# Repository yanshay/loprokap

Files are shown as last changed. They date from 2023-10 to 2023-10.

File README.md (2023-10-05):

# LoProKap

A wireless split keyboard with keys layout somewhat compatible with Kinesis Advantage Pro 360<sup>TM</sup>.
Designed using [Ergogen](https://ergogen.xyz/) and my [Ergogen Routing System](https://github.com/yanshay/ergogen-stuff)

> **Warning**
>
> This keyboard is still under development and not ready for manufacturing.

## Background

I own a [Kinesis Advantage Pro 360 keyboard](https://kinesis-ergo.com/shop/adv360pro/). 

With its concave structure, ergonomically it's a **great** keyboard but that costs in it not being very mobile.

Since I started using it I find it uncomfortable/confusing to use a standard keyboard when the Kinesis is not with me, so wanted to build a more mobile low profile keyboard that shares the same zmk configuration, and for that needed a compatible key layout. I also wanted keys to be layed out in a way that works on a non concave keyboard. This keyboard is the result.

The keyboard is developed using Ergogen and KiCad.

Ergogen is geat for layout of keys and other components however lacks any support for routing the PCB. With basic Ergogen usage every change in Ergogen cofig requires routing the keyboard from scratch.

Faced with that challenge, I developed a system for easy routing that complements Ergogen, where the routes are 'recorded' in Kicad as Ergogen footprint config using a KiCad plugin + routes are generated by Ergogen using the router footprint.

Both the KiCad Plugin and the Ergogen Footprint are available at https://github.com/yanshay/ergogen-stuff .

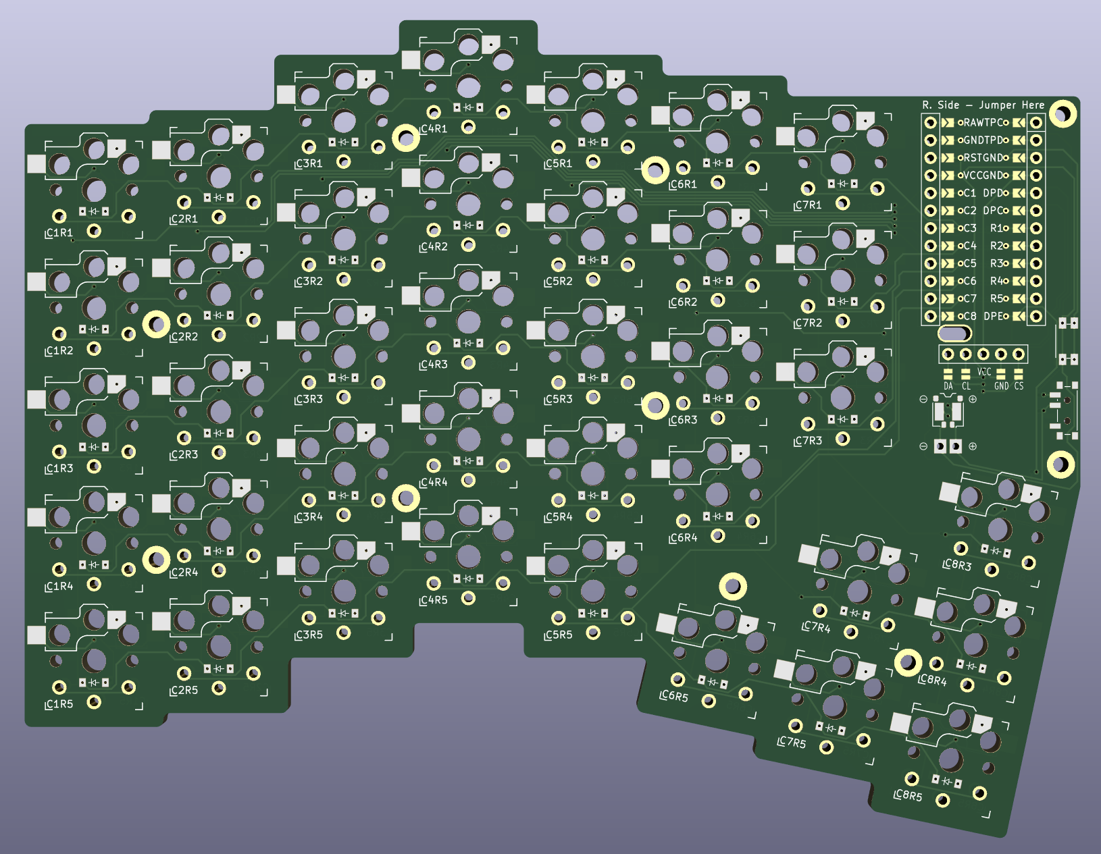
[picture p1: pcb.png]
Keyboard PCB Image


## Building the keyboard

1. Clone this repo
2. Change into the ergogen_src/footprints and execute the download_fps.sh to fetch the footprints from the relevant repositories
3. From the root folder run Build.sh
4. Output pcbs will be in pcbs folder (the repository already includes a version of the built pcb)

There are several scripts at the repo root that are specific to my systm folder structure that include some helpful functionality for easier workflow with Ergogen.

## Credits and Acknowledgements
- [Ergogen](https://ergogen.xyz/)

- [@infused-kim](https://github.com/infused-kim)
  - https://github.com/infused-kim/kb_ergogen_fp - basis for the footprints used, some of them were improved for this keyboard and therefore are in this repo
  - https://github.com/infused-kim/kb_think_corney - referenced used for learning
  - Thanks for the assistance over Ergogen Discord

- Everyone else who contributed to @infused-kim work and are mentioned in his repos, so indirectly contributed to this as well.

## License

**TLDR:**

- Personal use with attribution
- Commercial use not allowed
- Distribution under same license as the original

This work is licensed under a
[Creative Commons Attribution-ShareAlike 4.0 International License][cc-by-sa].

[][cc-by-sa]

[cc-by-sa]: http://creativecommons.org/licenses/by-sa/4.0/
[cc-by-sa-image]: https://licensebuttons.net/l/by-sa/4.0/88x31.png
[cc-by-sa-shield]: https://img.shields.io/badge/License-CC%20BY--SA%204.0-lightgrey.svg

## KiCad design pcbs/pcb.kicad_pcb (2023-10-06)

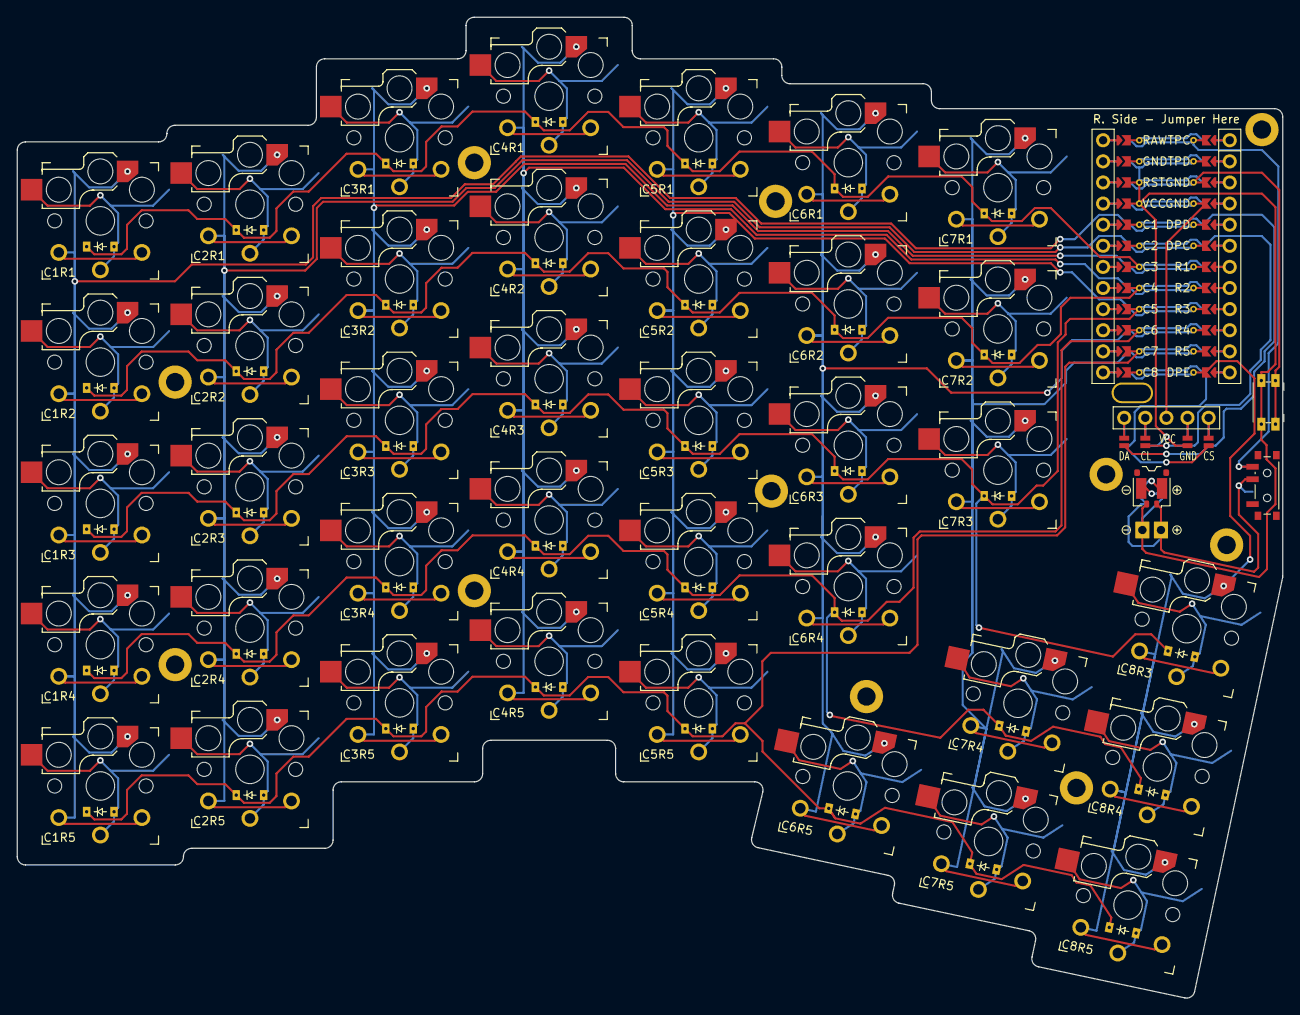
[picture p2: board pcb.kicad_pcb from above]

Board: 2 copper layers, 152.3 x 118.0 mm, 97 parts (0 on the bottom side), 63 nets.

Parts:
CONN1: conn_molex_pico_ezmate_1x02
D1, D2, D3, D4, D5, D6, D7, D8, D9, D10, D11, D12, D13, D14, D15, D16, D17, D18, D19, D20, D21, D22, D23, D24, D25, D26, D27, D28, D29, D30, D31, D32, D33, D34, D35, D36, D37, D38: ComboDiode
DISP1: nice!view
H1, H2, H3, H4, H5, H6, H7, H8, H9, H10, H11, H12: mounting_hole
ICON1, ICON2: icon_bat
MCU1: nice_nano
PAD1, PAD2: pads
S1, S2, S3, S4, S5, S6, S7, S8, S9, S10, S11, S12, S13, S14, S15, S16, S17, S18, S19, S20, S21, S22, S23, S24, S25, S26, S27, S28, S29, S30, S31, S32, S33, S34, S35, S36, S37, S38: PG1350
SW1: Panasonic_EVQPUJ_EVQPUA
SW2: power_switch

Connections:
BAT_P: CONN1.1, PAD1.1, PAD1.2, PAD2.1, SW2.2, SW2.5
C1: MCU1.5, S1.1, S2.1, S3.1, S4.1, S5.1
C2: MCU1.6, S6.1, S7.1, S8.1, S9.1, S10.1
C3: MCU1.7, S11.1, S12.1, S13.1, S14.1, S15.1
C4: MCU1.8, S16.1, S17.1, S18.1, S19.1, S20.1
C5: MCU1.9, S21.1, S22.1, S23.1, S24.1, S25.1
C6: MCU1.10, S26.1, S27.1, S28.1, S29.1, S33.1
C7: MCU1.11, S30.1, S31.1, S32.1, S34.1, S35.1
C8: MCU1.12, S36.1, S37.1, S38.1
DISP1_1: DISP1.1, DISP1.14, DISP1.27
DISP1_2: DISP1.2, DISP1.15, DISP1.26
DISP1_4: DISP1.4, DISP1.16, DISP1.25
DISP1_5: DISP1.5, DISP1.17, DISP1.24
DPC: DISP1.11, DISP1.21, MCU1.119
DPD: DISP1.10, DISP1.20, MCU1.120
DPE: DISP1.13, DISP1.23, MCU1.113
GND: CONN1.2, DISP1.12, DISP1.22, MCU1.2, MCU1.121, MCU1.122, PAD1.1, PAD1.2, PAD2.2, SW1.1
R1: D5.1, D10.1, D15.1, D20.1, D25.1, D29.1, D32.1, MCU1.118
R2: D4.1, D9.1, D14.1, D19.1, D24.1, D28.1, D31.1, MCU1.117
R3: D3.1, D8.1, D13.1, D18.1, D23.1, D27.1, D30.1, D38.1, MCU1.116
R4: D2.1, D7.1, D12.1, D17.1, D22.1, D26.1, D35.1, D37.1, MCU1.115
R5: D1.1, D6.1, D11.1, D16.1, D21.1, D33.1, D34.1, D36.1, MCU1.114
RAW: MCU1.1, SW2.3, SW2.6
RST: MCU1.3, SW1.2
VCC: DISP1.3, MCU1.4
far_bottom: D36.1, S36.2
far_over: D38.1, S38.2
far_top: D37.1, S37.2
index_bottom: D21.1, S21.2
index_home: D23.1, S23.2
index_low: D22.1, S22.2
index_num: D25.1, S25.2
index_top: D24.1, S24.2
inner_home: D27.1, S27.2
inner_low: D26.1, S26.2
inner_num: D29.1, S29.2
inner_top: D28.1, S28.2
mid_bottom: D34.1, S34.2
mid_top: D35.1, S35.2
middle_bottom: D16.1, S16.2
middle_home: D18.1, S18.2
middle_low: D17.1, S17.2
middle_num: D20.1, S20.2
middle_top: D19.1, S19.2
near_bottom: D33.1, S33.2
outer_bottom: D1.1, S1.2
outer_home: D3.1, S3.2
outer_low: D2.1, S2.2
outer_num: D5.1, S5.2
outer_top: D4.1, S4.2
pinky_bottom: D6.1, S6.2
pinky_home: D8.1, S8.2
pinky_low: D7.1, S7.2
pinky_num: D10.1, S10.2
pinky_top: D9.1, S9.2
ring_bottom: D11.1, S11.2
ring_home: D13.1, S13.2
ring_low: D12.1, S12.2
ring_num: D15.1, S15.2
ring_top: D14.1, S14.2
superinner_home: D30.1, S30.2
superinner_num: D32.1, S32.2
superinner_top: D31.1, S31.2

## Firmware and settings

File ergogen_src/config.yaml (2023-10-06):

units:
  kx: cx
  ky: cy
  px: 0.0
  py: 0.0
  kpx: kx+px
  kpy: ky+py
  step: .5

  pinky_stagger: 2
  ring_stagger: 8
  middle_stagger: 5
  index_stagger: -5
  inner_stagger: -3
  superinner_stagger: -3

  mounting_hole_outline: 0.9
  mounting_hole_drill: 2.2

  # Nice Nano
  # The nice nano footprint's center doesn't account
  mcu_spacing_left: 1.25
  mcu_spacing_right: 1.5
  mcu_x: 17.78
  mcu_y: 33.0
  mcu_xo: 0.5 * mcu_x
  mcu_yo: 0.5 * mcu_y

  # Display Cover Holes
  display_cover_hole_outline: 0.9
  display_cover_hole_drill: 2.2
  display_cover_hole_x: display_cover_hole_drill + display_cover_hole_outline * 2
  display_cover_hole_y: display_cover_hole_x
  display_cover_hole_xo: 0.5 * display_cover_hole_x
  display_cover_hole_yo: 0.5 * display_cover_hole_y
  display_cover_hole_mcu_distance_y: -13.5
  display_cover_hole_distance_x: 14.5
  display_cover_hole_distance_xo: 0.5 * display_cover_hole_distance_x
  display_cover_hole_distance_y: -8.5
  display_cover_hole_offset_y_to_not_hit_thumb_key: 2.5
points:
  key:
    padding: kpy
    spread: kpx
    height: 16.5
    width: 17.5
  zones:
    matrix:
      key:
        tags: key
      anchor:
        shift: [100, -200]
      columns:
        outer:
          key.column_net: C1
        pinky:
          key.stagger: pinky_stagger
          key.column_net: C2
        ring:
          key.stagger: ring_stagger
          key.column_net: C3
        middle:
          key.stagger: middle_stagger
          key.column_net: C4
        index:
          key.stagger: index_stagger 
          key.column_net: C5
          rows.top.tags: [key] # , above_rotated_key]
          rows.home.tags: [key] #, rotated_key]
        inner:
          key.stagger: inner_stagger
          rows.bottom.skip: true
          key.column_net: C6
          rows.top.tags: [key] # , above_rotated_key]
          rows.home.tags: [key] # , rotated_key]
        superinner:
          key.stagger: superinner_stagger
          rows.bottom.skip: true
          rows.low.skip: true
          key.column_net: C7
      rows:
        bottom:
          row_net: R5
        low:
          row_net: R4
        home:
          row_net: R3
        top:
          row_net: R2
        num:
          row_net: R1
    thumb:
      key:
        tags: key
      anchor:
        ref: matrix_inner_bottom
        shift: [-0.1, -7]
        rotate: -12
      columns:
        near:
          key.column_net: C6
          rows.top.skip: true
          rows.over.skip: true
        mid:
          key.stagger: -3
          key.column_net: C7
          rows.over.skip: true
        far:
          key.stagger: -4
          key.column_net: C8
          key.spread: kpx
      rows:
        bottom:
          row_net: R5
        top:
          row_net: R4
        over:
          row_net: R3

################## Helper Points    

    board_mid_right_corner:
      anchor:
        - ref: thumb_far_over
          shift: [kpx/2+1, kpy/2]
          affect: [x,y]

    board_top_right:
      anchor:
        - ref: board_mid_right_corner
          affect: x
        - ref: matrix_superinner_num
          shift: [kpx+15.3+1, kpy/2+1]
          affect: y

    nano:
      anchor:
        - ref: board_top_right
          shift: [-14, -16.5]

    view:
      anchor:
        - ref: nano
          shift: [0, -4.0]

    power_switch:
      anchor:
        - ref: board_mid_right_corner
          shift: [0, 11]
          affect: y
        - ref: board_top_right
          shift: [-1.9, 0]
          affect: x

    reset_switch:
      anchor:
        - ref: power_switch
          shift: [0.175, 10]

    bat_connector_hole:
      anchor:
        - ref: nano
          shift: [-4.1,-17.7]

    bat_connector:
      anchor:
        - ref: nano
          shift: [-5.1+3.325,-29-0.2]
          rotate: 180

    bat_solder_pads:
      anchor:
        - ref: bat_connector_hole 
          shift: [8 , -11]
          affect: [x, y]

    # Display Cover Holes
    display_cover_hole_left:
      anchor:
        ref: nano 
        shift: [-display_cover_hole_distance_xo, -mcu_yo + display_cover_hole_mcu_distance_y + display_cover_hole_offset_y_to_not_hit_thumb_key]
      key:
        name: display_cover_hole_left
        tags: display_cover_hole

    display_cover_hole_right:
      anchor:
        ref: display_cover_hole_left
        shift: [+display_cover_hole_distance_x, display_cover_hole_distance_y]
      key.tags: display_cover_hole

    # trackpoint_mount:
    #   anchor:
    #     ref.aggregate.parts:
    #       - matrix_index_top
    #       - matrix_index_home
    #       - matrix_inner_top
    #       - matrix_inner_home
    #     affect: [x, y]
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

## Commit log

2023-10-05 Initial commit - first working version
    [bottom_plate.kicad_pcb, pcb.kicad_pcb]
2023-10-05 switched to download footprints from my fork of infused-kim footprints
2023-10-05 added image of pcb to readme
2023-10-05 update pcb and image
    [pcb.kicad_pcb]
2023-10-05 fixed one router footprint that wasn't locked
    [pcb.kicad_pcb]
2023-10-05 updated kicad_pro with jclpcb capabilities
2023-10-05 remove gerber from git
2023-10-05 added display cover mount holes and reorganized around to fit
    [pcb.kicad_pcb]
2023-10-06 some routing improvements and mounting holes adjustments
    [pcb.kicad_pcb]
